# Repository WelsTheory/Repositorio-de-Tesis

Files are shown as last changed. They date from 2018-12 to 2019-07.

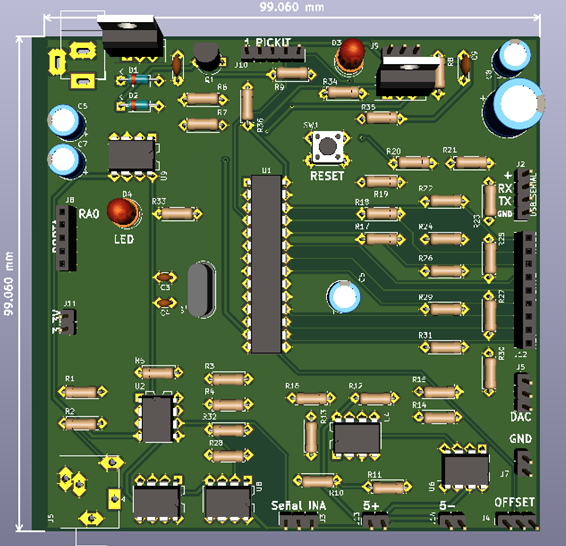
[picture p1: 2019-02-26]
Tarjeta de Adquisición de investigación.png

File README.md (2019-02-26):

# Diseño e implementación de un sistema de adquisición digital programable para señales ECG
Repositorio de la tesis "Diseño e implementación de un sistema de adquisición digital programable para señales ECG". Autor: William's Limonchi Sandoval
## Requisitos
Es necesario tener instalado los siguientes programas:
* [Matlab](https://www.mathworks.com/products/matlab.html) - La versión 2014 o superior
* [XC16](https://www.microchip.com/mplab/compilers) - El compilador XC16 para generar el programa del microcontrolador
* [Device Blocks for Simulink](https://www.microchip.com/forums/m878432.aspx) - Herramienta para trabajar con Microchip en Simulink
También es necesario tener la tarjeta de adquisición de la investigación para poder trabajar con el sistema. Los archivos de la tarjeta se encuentran en la carpeta Demo SAQD_ECG/Diseño Hardware_KiCad
### Carpetas del repositorio
* Carpeta de pruebas:
En esta carpeta se encuentran todos los ejemplos realizados antes de obtener el trabajo final
* Demo SAQD_ECG:
En esta carpeta se encuentra el programa principal de la tesis, desde el diseño de hardware de la investigación hasta el programa final con su interfaz gráfica.
* Ejemplos:
En esta carpeta se encuentran diferentes ejemplos que se han unido con el sistema. 
1) Downsamplin, para obtener otro tiempo de muestreos.
2) Filtros butterworth, para saber como trabajan los filtros butterworth con la investigación.
3) Filtros de 1er orden, son filtros sencillos de 1er orden para saber como trabaja la investigación
4) Sistema con tres filtros, es el programa principal con sólo 3 filtros.
5) Sistema con un único filtro, es el programa principal con un único filtro.
Estos programas son ejemplos para modificar el bloque Programable del programa principal. 
* Framework:
En esta carpeta se encuentra una copia del programa principal de la investigación, esto para poder modificar este programa sin necesidad de causar un error en el demo de la investigación.
## Contribución
Para contribuir con la investigación primero se debe hacer un fork al repositorio y seguidamente se puede enviar los cambios o modificaciones al correo: williams.limonchi.sandoval@gmail.com
## Version 
Esta investigación está en la versión 1.0.1 por lo que aún hay detalles que pulir y mejorar.
## Autor
William's Limonchi Sandoval [Twitter](http://twitter.com/welstheory)

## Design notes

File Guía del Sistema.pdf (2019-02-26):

Guía del Sistema

Para acceder a la investigación puedes entrar al siguiente enlace:

https://github.com/WelsTheory/Repositorio-de-Tesis o agregar el enlace ssh:

git@github.com:WelsTheory/Repositorio-de-Tesis.git para poder hacer un fork a la

investigación.

En la investigación encontrarás los siguientes archivos:

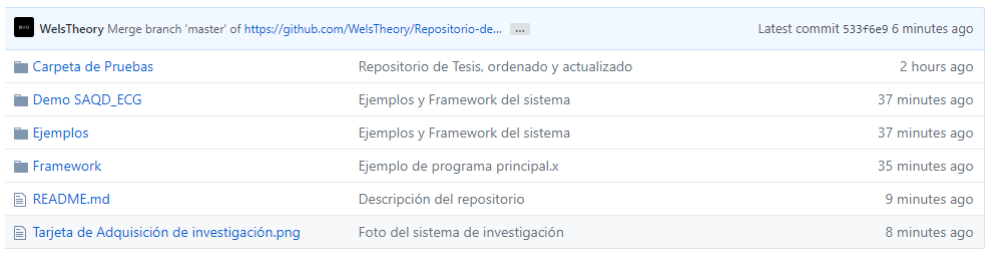
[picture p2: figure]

- Carpeta de pruebas: En esta carpeta se encuentran todos los ejemplos realizados

antes de obtener el trabajo final

- Demo SAQD_ECG: En esta carpeta se encuentra el programa principal de la tesis,

desde el diseño de hardware de la investigación hasta el programa final con su

interfaz gráfica.

- Ejemplos: En esta carpeta se encuentran diferentes ejemplos que se han unido con

el sistema.

✓ | Downsamplin, para obtener otro tiempo de muestreos.
✓ | Filtros butterworth, para s realizar prueba con los filtros butterworth y la
| investigación.
✓ | Filtros de 1er orden, son filtros sencillos de 1er orden para realizar prueba con
| la investigación
✓ | Sistema con tres filtros, es el programa principal con sólo 3 filtros.

✓ | Sistema con un único filtro, es el programa principal con un único filtro. Estos
| programas son ejemplos para modificar el bloque Programable del programa
| principal.
- Framework: En esta carpeta se encuentra una copia del programa principal de la

investigación, esto para poder modificar este programa sin necesidad de causar un

error en el demo de la investigación.

Requisitos:

Es necesario tener instalado los siguientes programas:

- Matlab (https://www.mathworks.com/products/matlab.html) - La versión 2014 o superior
- XC16 (https://www.microchip.com/mplab/compilers) - El compilador XC16 para generar el programa del microcontrolador
- Device Blocks for Simulink (https://www.microchip.com/forums/m878432.aspx) - Herramienta para trabajar con Microchip en Simulink

También es necesario tener la tarjeta de adquisición de la investigación para poder

trabajar con el sistema. Los archivos de la tarjeta se encuentran en la carpeta Demo

SAQD_ECG/Diseño Hardware_KiCad

Primeros pasos para programar el microcontrolador:

1) Abrir el programa Tesis_Simulink.slx que se encuentra en la carpeta Demo SAQD_ECG

para visualizar el programa completo y principal de la investigación:

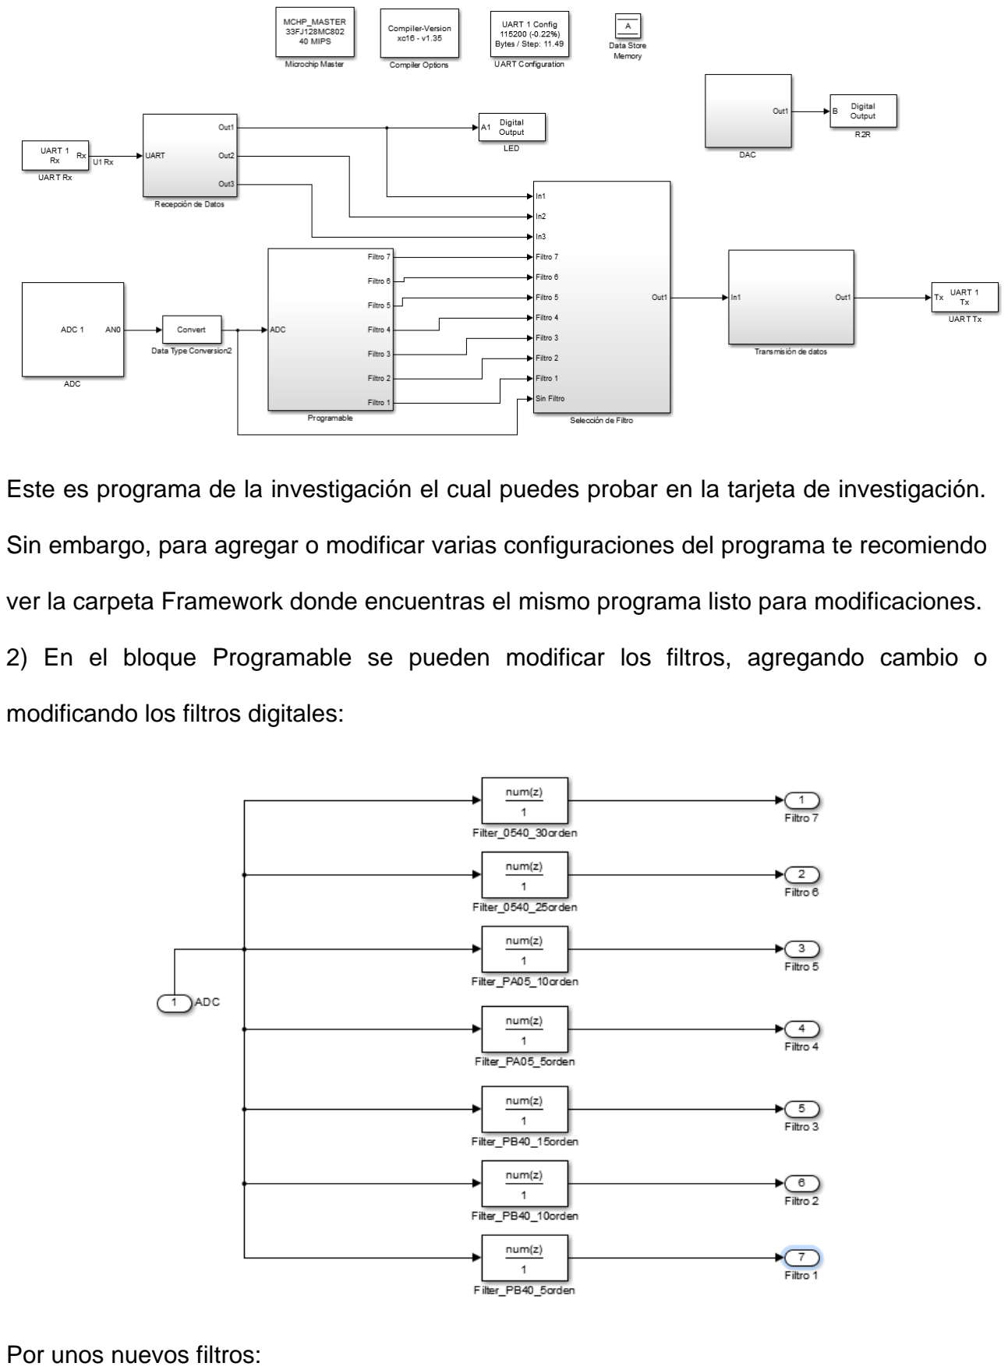
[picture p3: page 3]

Este es programa de la investigación el cual puedes probar en la tarjeta de investigación.

Sin embargo, para agregar o modificar varias configuraciones del programa te recomiendo

ver la carpeta Framework donde encuentras el mismo programa listo para modificaciones.

2) En el bloque Programable se pueden modificar los filtros, agregando cambio o

modificando los filtros digitales:

Por unos nuevos filtros:

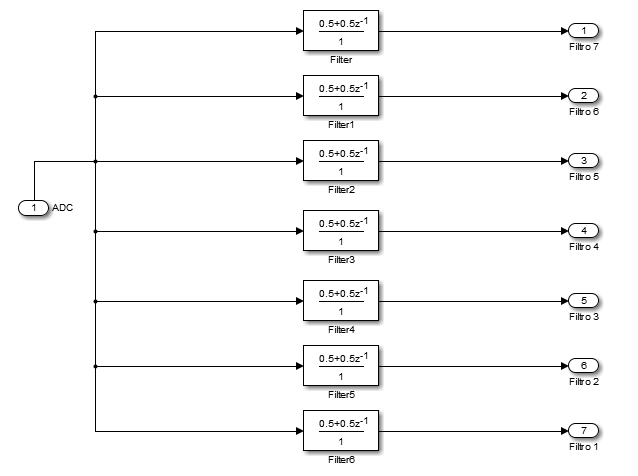
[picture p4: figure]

O quitando algunos filtros:

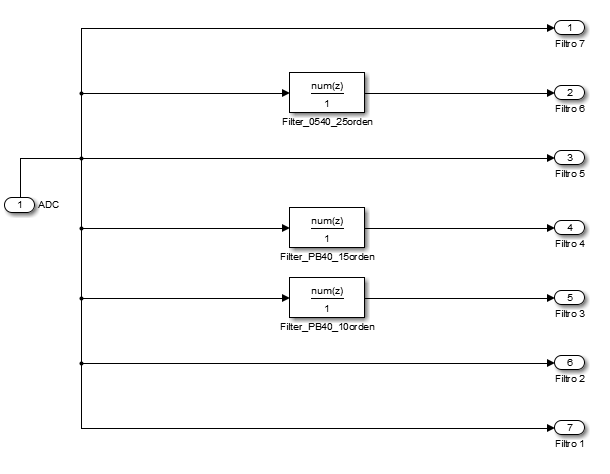
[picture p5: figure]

En la carpeta Ejemplos del repositorio, puedes encontrar más ejemplos de diferentes filtros

que se pueden utilizar o cambiar en el bloque Programable:

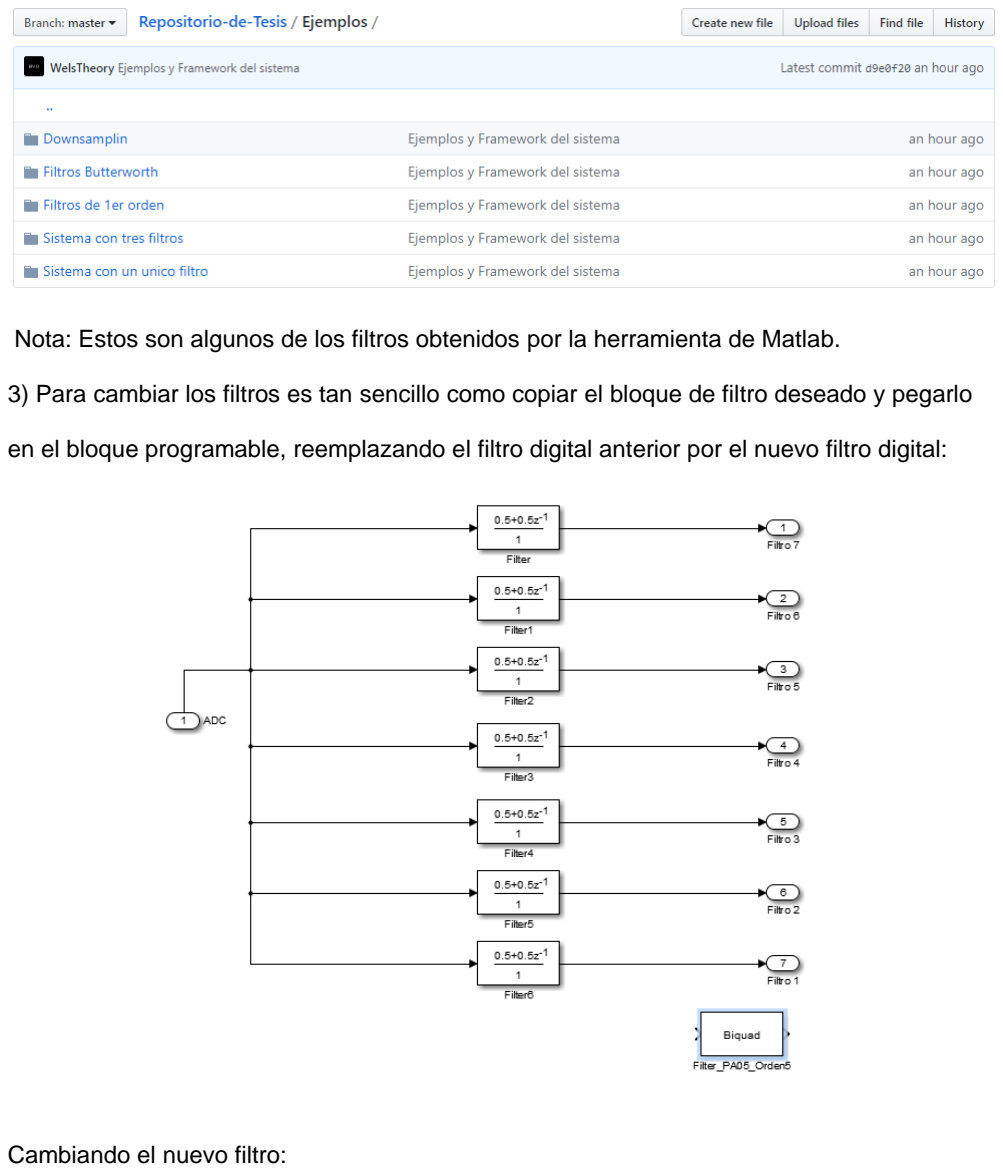
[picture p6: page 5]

Nota: Estos son algunos de los filtros obtenidos por la herramienta de Matlab.

3) Para cambiar los filtros es tan sencillo como copiar el bloque de filtro deseado y pegarlo

en el bloque programable, reemplazando el filtro digital anterior por el nuevo filtro digital:

Cambiando el nuevo filtro:

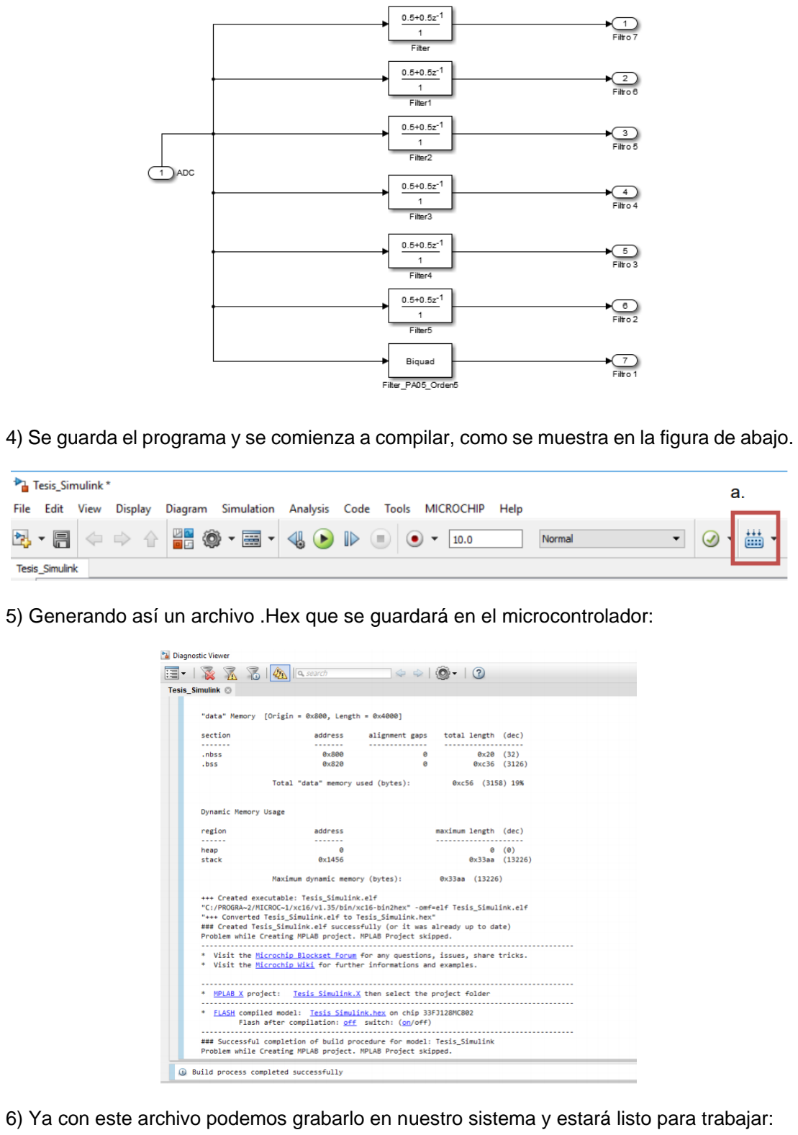
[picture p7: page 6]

4) Se guarda el programa y se comienza a compilar, como se muestra en la figura de abajo.
5) Generando así un archivo .Hex que se guardará en el microcontrolador:
6) Ya con este archivo podemos grabarlo en nuestro sistema y estará listo para trabajar:

Nota: Recordar que para este poder modificar el programa y los filtros es necesario

tener una versión de Matlab 2014 o superior, así como tener instalado el Compilador

XC16 de Microchip y Mplab 16-bit Device Blocks for Simulink v3.37 Released. Forum

Microchip

En la fecha de febrero del 2019 el programa se encuentra en la versión 1.0 por lo que

en el tiempo este apéndice puede ir modificándose.

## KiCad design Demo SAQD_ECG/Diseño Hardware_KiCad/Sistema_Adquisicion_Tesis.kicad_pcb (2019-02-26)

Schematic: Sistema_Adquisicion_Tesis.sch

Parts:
C1, C9: 100nF; C_Disc_D4.3mm_W1.9mm_P5.00mm
C2: 220uF; CP_Radial_D10.0mm_P5.00mm
C3, C4: 15pF; C_Disc_D3.0mm_W1.6mm_P2.50mm
C5, C6, C7, C8: 10uF; CP_Radial_D6.3mm_P2.50mm
D1, D2: 1N4148; D_DO-35_SOD27_P7.62mm_Horizontal
D3, D4: LED; LED_D5.0mm
J1: Barrel_Jack_Switch; Jack_Horizontal
J2: USB_SERIAL; PinHeader_1x04_P2.54mm_Vertical
J3: Signal_INA; PinHeader_1x03_P2.54mm_Vertical
J4: Offset; PinHeader_1x03_P2.54mm_Vertical
J5: Electrodos; Jack_3.5mm_Ledino_KB3SPRS_Horizontal
J6: DAC; PinHeader_1x03_P2.54mm_Vertical
J7: GND; PinHeader_1x02_P2.54mm_Vertical
J8: PORTA; PinSocket_1x05_P2.54mm_Vertical
J9: S_Fuente; PinHeader_1x03_P2.54mm_Vertical
J10: Pickit; PinHeader_1x05_P2.54mm_Vertical
J11: 3.3v; PinHeader_1x02_P2.54mm_Vertical
J12: PORTB; PinSocket_1x09_P2.54mm_Vertical
J13: V+; PinHeader_1x02_P2.54mm_Vertical
J14: V-; PinHeader_1x02_P2.54mm_Vertical
Q1: 2N3906; TO-92L_Inline_Wide
R1, R2: 1k; R_Axial_DIN0207_L6.3mm_D2.5mm_P7.62mm_Horizontal
R3, R4: 2k; R_Axial_DIN0207_L6.3mm_D2.5mm_P7.62mm_Horizontal
R5, R33, R35: 220; R_Axial_DIN0207_L6.3mm_D2.5mm_P7.62mm_Horizontal
R6, R7, R12: 5.6k; R_Axial_DIN0207_L6.3mm_D2.5mm_P7.62mm_Horizontal
R8, R19, R21, R23, R25, R27, R30, R36: 10k; R_Axial_DIN0207_L6.3mm_D2.5mm_P7.62mm_Horizontal
R9: 470; R_Axial_DIN0207_L6.3mm_D2.5mm_P7.62mm_Horizontal
R10, R11, R13, R14, R15, R16, R32: 1K; R_Axial_DIN0207_L6.3mm_D2.5mm_P7.62mm_Horizontal
R17, R18, R20, R22, R24, R26, R29, R31: 20k; R_Axial_DIN0207_L6.3mm_D2.5mm_P7.62mm_Horizontal
R28: 10K; R_Axial_DIN0207_L6.3mm_D2.5mm_P7.62mm_Horizontal
R34: 390; R_Axial_DIN0207_L6.3mm_D2.5mm_P7.62mm_Horizontal
SW1: RESET; SW_PUSH_6mm
U1: dsPIC33FJ128MC802-E_SP; DIP-28_W7.62mm
U2: INA128; DIP-8_W7.62mm
U3: L7805; TO-220-3_Vertical
U4, U7: TL082; DIP-8_W7.62mm
U5: LM317L_TO92; TO-220-3_Vertical
U6, U8: OP07; DIP-8_W7.62mm
U9: ADM660AN; DIP-8_W7.62mm
Y1: 10MHZ; Crystal_HC50_Vertical

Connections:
/3+: C9.1, J9.3, R35.2, U5.2
/3.3: J9.2, J11.1, J11.2, R36.2, U1.13, U1.28
/+IN: J5.T, J5.TN, R2.1
/-IN: J5.S, R1.1
/MCLR: J10.1, R36.1, SW1.1, U1.1
/OUT1: J3.2, R10.1
/OUT2: J4.3, U6.2, U6.6
/RA0: J4.2, J8.1, U1.2
/RA1: J8.2, R33.2, U1.3
/RA2: C3.1, J8.3, U1.9, Y1.1
/RA3: C4.1, J8.4, U1.10, Y1.2
/RA4: J8.5, U1.12
/RB0: J10.4, R18.1, U1.4
/RB1: J10.5, R20.1, U1.5
/RB2: R22.1, U1.6
/RB3: R24.1, U1.7
/RB4: R26.1, U1.11
/RB5: R29.1, U1.14
/RB6: R31.1, U1.15
/RB7: J12.1, U1.16
/RB8: J12.2, U1.17
/RB9: J12.3, U1.18
/RB12: J12.6, U1.23
/RB13: J12.7, U1.24
/RB14: J12.8, U1.25
/RB15: J12.9, U1.26
/RX: J2.2, J12.4, U1.21
/TC: J5.R, J5.RN, R28.1, U7.1
/TX: J2.3, J12.5, U1.22
/V+: C2.1, C8.1, D2.1, J13.1, J13.2, Q1.3, R9.1, R12.1, U2.7, U4.8 (V+), U5.3, U6.7, U7.8 (V+), U8.7, U9.8
/V-: C7.1, J14.1, J14.2, U2.4, U4.4 (V-), U6.4, U7.4 (V-), U8.4, U9.5
/Vp: J9.1, J10.2
/Vusb: J2.1, Q1.1, R8.1
/WCT: R3.1, R4.1, U8.3
GND: C1.2, C2.2, C3.2, C4.2, C5.1, C7.2, C8.2, C9.2, D1.1, D3.1, D4.1, J1.2, J1.3, J2.4, J3.1, J4.1, J6.1, J7.1, J7.2, J10.3, R6.2, R8.2, R15.2, R17.2, R34.1, SW1.2, U1.8, U1.19, U1.27, U2.5, U4.3 (+), U7.3 (+), U9.3
unnamed: C1.1, D2.2, R6.1, R7.1, U3.3
unnamed: C5.2, U1.20
unnamed: C6.1, U9.2
unnamed: C6.2, U9.4
unnamed: D1.2, U3.2
unnamed: D3.2, R9.2
unnamed: D4.2, R33.1
unnamed: J1.1, U3.1
unnamed: J3.3, U2.6
unnamed: J6.2, J6.3, R30.1, R31.2
unnamed: Q1.2, R7.2
unnamed: R1.2, U2.2
unnamed: R2.2, U2.3
unnamed: R3.2, R5.1, U2.1
unnamed: R4.2, R5.2, U2.8
unnamed: R10.2, R11.1, U4.2 (-)
unnamed: R11.2, R13.1, U4.1
unnamed: R12.2, R14.1, R15.1
unnamed: R13.2, R16.1, U4.6 (-)
unnamed: R14.2, U4.5 (+)
unnamed: R16.2, U4.7, U6.3
unnamed: R17.1, R18.2, R19.2
unnamed: R19.1, R20.2, R21.2
unnamed: R21.1, R22.2, R23.2
unnamed: R23.1, R24.2, R25.2
unnamed: R25.1, R26.2, R27.2
unnamed: R27.1, R29.2, R30.2
unnamed: R28.2, R32.1, U7.2 (-)
unnamed: R32.2, U8.2, U8.6
unnamed: R34.2, R35.1, U5.1

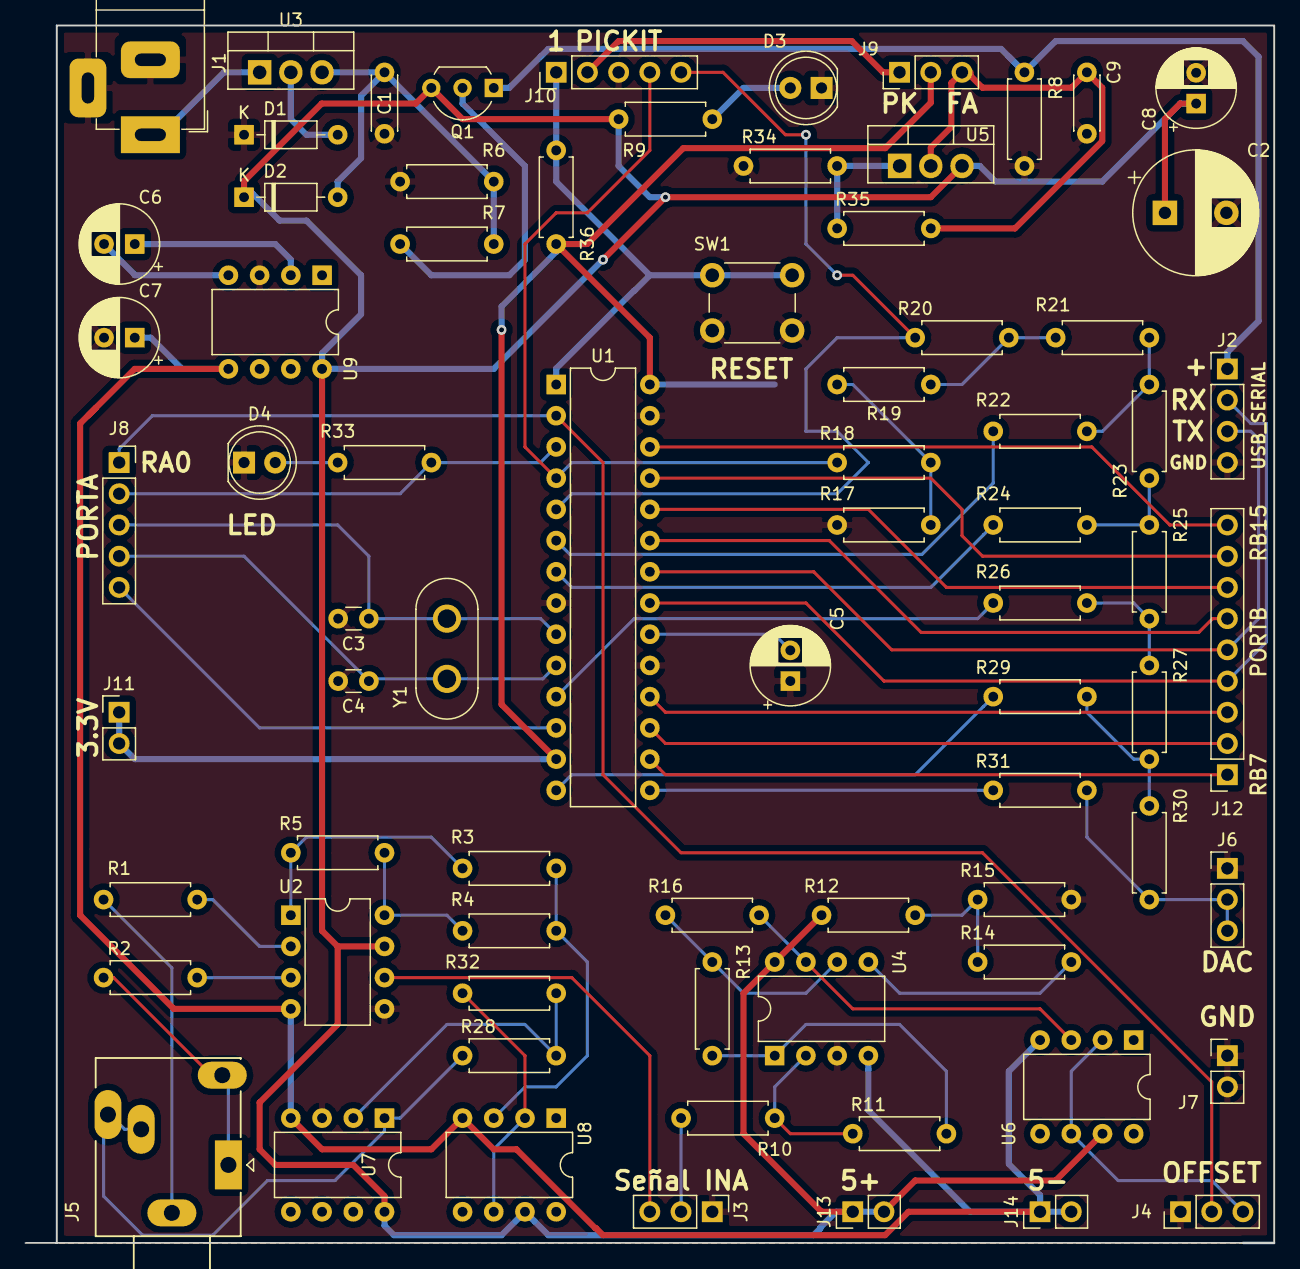
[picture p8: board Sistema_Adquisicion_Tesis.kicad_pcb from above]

Board: 2 copper layers, 101.6 x 99.1 mm, 75 parts (0 on the bottom side), 65 nets.

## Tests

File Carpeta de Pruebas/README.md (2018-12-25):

# Repositorio-de-Tesis
Diseño e implementación de un sistema de adquisición digital programable para señal ECG. Autor:William's Limonchi Sandoval

## Primeros pasos

Por el momento encontrarás una carpeta que se llama "Carpeta de Pruebas", en esta carpeta se está constantemente probando y desarrollando todos los programas para la versión final de la tesis. 

### Requisitos

Necesitas tener instalados algunos programas en tu computadora para iniciar:

```
Matlab desde la versión 2014 en adelante
Mplab Simulink (https://www.microchip.com/DevelopmentTools/ProductDetails/sw007023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)

```

### Plantilla para ir agregando en un futuro

A step by step series of examples that tell you how to get a development env running

Say what the step will be

```
Give the example
```

And repeat

```
until finished
```

End with an example of getting some data out of the system or using it for a little demo

## Running the tests

Explain how to run the automated tests for this system

### Break down into end to end tests

Explain what these tests test and why

```
Give an example
```

### And coding style tests

Explain what these tests test and why

```
Give an example
```

## Deployment

Add additional notes about how to deploy this on a live system

## Built With

* [Dropwizard](http://www.dropwizard.io/1.0.2/docs/) - The web framework used
* [Maven](https://maven.apache.org/) - Dependency Management
* [ROME](https://rometools.github.io/rome/) - Used to generate RSS Feeds

## Contributing

Please read [CONTRIBUTING.md](https://gist.github.com/PurpleBooth/b24679402957c63ec426) for details on our code of conduct, and the process for submitting pull requests to us.

## Versioning

We use [SemVer](http://semver.org/) for versioning. For the versions available, see the [tags on this repository](https://github.com/your/project/tags). 

## Authors

* **Billie Thompson** - *Initial work* - [PurpleBooth](https://github.com/PurpleBooth)

See also the list of [contributors](https://github.com/your/project/contributors) who participated in this project.

## License

This project is licensed under the MIT License - see the [LICENSE.md](LICENSE.md) file for details

## Acknowledgments

* Hat tip to anyone whose code was used
* Inspiration
* etc

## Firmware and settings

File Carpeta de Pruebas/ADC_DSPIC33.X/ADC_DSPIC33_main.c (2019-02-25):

/*
 * -------------------------------------------------------------------
 * MPLAB 16-Bit Device Blocks for Simulink v3.38.
 *
 *   Product Page:  http://www.microchip.com/SimulinkBlocks
 *           Forum: http://www.microchip.com/forums/f192.aspx
 *           Wiki:  http://microchip.wikidot.com/simulink:start
 * -------------------------------------------------------------------
 * File: ADC_DSPIC33_main.c
 *
 * Code generated for Simulink model 'ADC_DSPIC33'.
 *
 * Model version                  : 1.202
 * Simulink Coder version         : 8.6 (R2014a) 27-Dec-2013
 * C/C++ source code generated on : Sun Nov 18 19:15:44 2018
 */

#define MCHP_isMainFile
#include "ADC_DSPIC33.h"
#include "ADC_DSPIC33_private.h"

volatile uint_T ContinueTimeStep __attribute__ ((near)) = 0;/* Microchip Global Variable for single rate scheduler */

/* Microchip Global Variables */
/* Set Fuses Options */
#pragma config FNOSC = PRI, IESO = OFF
#pragma config POSCMD = HS, FCKSM = CSECMD
#pragma config FWDTEN = OFF
#pragma config FPWRT = PWR1
#pragma config JTAGEN = OFF

/* Solver mode : SingleTasking */
int main()
{
  /* Initialize model */
  /* Start Clock Switching */
  if ((OSCCONbits.COSC & 1) && !(OSCCONbits.COSC & 4))/* check not already in PLL mode (0?1) */
  {
    __builtin_write_OSCCONH(0);        /* Clock Switch to non PLL mode */
    __builtin_write_OSCCONL(0x01);     /* Start clock switching */
    __asm__ volatile("nop\n"
                     "nop");
    while (OSCCONbits.COSC != 0) ;
  }

  PLLFBD = 110.0;                      /* configure Oscillator PLL : PLLDIV */
  CLKDIV = 0x05;                       /* configure Oscillator PLL : FRCDIV ; PLLPOST ; PLLPRE */
  __builtin_write_OSCCONH(3);          /* Clock Switch to desired configuration */
  __builtin_write_OSCCONL(0x01);       /* Start clock switching */

  /* Configure Pins as Analog or Digital */
  AD1PCFGL = 0x1A;

  /* Configure Remappables Pins */
  RPINR18 = 0x0A;
  RPOR5 = 0x0300;

  /* Configure Digitals I/O directions */
  TRISA = 0xFFFD;
  TRISB = 0xF7F9;

  /* Finish clock switching procedure */
  while (OSCCONbits.COSC != 3) ;       /* Wait for Oscillator Stabilisation */
  while (OSCCONbits.LOCK != 1) ;       /* Wait for PLL Stabilisation */

  /* Initialize model */
  ADC_DSPIC33_initialize();

  /* Configure Timers */
  /* --- TIMER 3 --- This timer is enabled at end of configuration functions. */
  T3CON = 0;                           /* Stop Timer 3 and resets control register */
  PR3 = 0x9C3F;                        /* Period */

  /* Enable Time-step */
  _T3IF = 0;                           /* Clear Timer 3 Interrupt flag */
  _T3IE = 1;                           /* Enable Timer 3 model Step Interrupt */
  TMR3 = 0x9C3E;
  T3CONbits.TON = 1;                   /* Start timer 3. Timer 3 is the source trigger for the model Time-step */

  /* Main Loop */
  for (;;) {
    while (!ContinueTimeStep) ;

    /* Disable Scheduler Interrupt */
    _IPL0 = 1;                         /* Disable Scheduler Interrupts. Rise IPL from 0 to 1 */
    __asm__ volatile ("BCLR.b %[MyVar], #0" : [MyVar] "+m" (ContinueTimeStep) );/* Atomic bit-clear of ContinueTimeStep bit 1 */

    /* Call model Scheduler */
    /* Step the model for base rate */
    /* Start profiling task 0 */
    ADC_DSPIC33_step();

    /* Get model outputs here */

    /* Stop profiling task 0 */

    /* Re-Enable Scheduler Interrupt */
    _IPL0 = 0;                         /* Re-Enable Scheduler re-entrant interrupt. Lower IPL from 1 to 0 */
  }                                    /* End for(;;) */
}

/*
 * File trailer for generated code.
 *
 * [EOF]
 */

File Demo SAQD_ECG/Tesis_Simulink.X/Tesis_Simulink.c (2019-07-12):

/*
 * -------------------------------------------------------------------
 * MPLAB 16-Bit Device Blocks for Simulink v3.38.
 *
 *   Product Page:  http://www.microchip.com/SimulinkBlocks
 *           Forum: http://www.microchip.com/forums/f192.aspx
 *           Wiki:  http://microchip.wikidot.com/simulink:start
 * -------------------------------------------------------------------
 * File: Tesis_Simulink.c
 *
 * Code generated for Simulink model 'Tesis_Simulink'.
 *
 * Model version                  : 1.143
 * Simulink Coder version         : 8.6 (R2014a) 27-Dec-2013
 * C/C++ source code generated on : Sun Jul 07 20:59:31 2019
 */

#include "Tesis_Simulink.h"
#include "Tesis_Simulink_private.h"

/* Block signals and states (auto storage) */
DW_Tesis_Simulink_T Tesis_Simulink_DW;

/* Model step function */
void Tesis_Simulink_step(void)
{
  /* local block i/o variables */
  boolean_T rtb_Compare;
  real32_T numAccum;
  real32_T denAccum;
  int32_T i;
  int32_T j;
  boolean_T rtb_Compare_m;
  real32_T rtb_DataTypeConversion7;
  real32_T rtb_Filtro_40Hz_Orden_20;
  real32_T rtb_Filtro_05Hz_Orden_2;
  real32_T rtb_Filtro_40Hz_Orden_5;
  real32_T rtb_Filtro_40Hz_Orden_15;
  real32_T rtb_Filtro_40Hz_Orden_30;

  /* MCHP_UART_Rx Block for UARTRef 1: <Root>/UART Rx/Outputs */
  {
    static uint8_T U1LastValue ;
    if (0U != U1STAbits.URXDA) {       /* Flush internal UART buffer */
      uint_T Tmp;
      _U1RXIE = 0;                     /* Flush internal UART buffer, disable interrupt */
      Tmp = ~(MCHP_UART1_Rx.tail - MCHP_UART1_Rx.head);/* head - tail - 1 */
      Tmp &= (Rx_BUFF_SIZE_Uart1-1);   /* Tmp =  (head - tail - 1) modulo buffersize Rx_BUFF_SIZE_Uart1)	<==> Rx_BUFF_SIZE_Uart1 - (head - tail) - 1*/
      while (U1STAbits.URXDA == 1) {
        if (Tmp--) {
          MCHP_UART1_Rx.buffer[MCHP_UART1_Rx.tail] = (uint8_T) U1RXREG;
          MCHP_UART1_Rx.tail = (MCHP_UART1_Rx.tail+1) & (Rx_BUFF_SIZE_Uart1-1);
        } else {
          unsigned int a;
          do
            a = U1RXREG;
          while (U1STAbits.URXDA == 1);
          break;
        }
      }

      _U1RXIF = 0;                     /* Reset interrupt */
      _U1RXIE = 1;                     /* Re-enable interrupt */
    }

    if (MCHP_UART1_Rx.tail != MCHP_UART1_Rx.head) {
      Tesis_Simulink_DW.U1Rx = (uint8_T) MCHP_UART1_Rx.buffer[MCHP_UART1_Rx.head];/* Use only the 8 low bytes or RxReg */
      MCHP_UART1_Rx.head = (MCHP_UART1_Rx.head+1) & (Rx_BUFF_SIZE_Uart1-1);
      U1LastValue = Tesis_Simulink_DW.U1Rx;
    } else {
      Tesis_Simulink_DW.U1Rx = U1LastValue;
      if (U1STAbits.OERR )
        U1STAbits.OERR = 0;            /* Clear UART Rx Overload Error */
    }
  }

  /* RelationalOperator: '<S6>/Compare' incorporates:
   *  Constant: '<S6>/Constant'
   *  S-Function (sfix_bitop): '<S3>/Bitwise Operator2'
   */
  rtb_Compare = ((Tesis_Simulink_DW.U1Rx & 1) == 1);

  /* S-Function (MCHP_Digital_Output_Write): '<S1>/Digital Output Write' */
  LATAbits.LATA1 = rtb_Compare;

  /* MCHP_ADC Block for ADC 1: <Root>/ADC/Output */
  Tesis_Simulink_DW.ADC = ADC1BuffChannelA[0];

  /* DataTypeConversion: '<Root>/Data Type Conversion2' */
  Tesis_Simulink_DW.DataTypeConversion2 = Tesis_Simulink_DW.ADC;

  /* S-Function (sdspbiquad): '<S2>/Filtro_40Hz_Orden_5but' */
  denAccum = (0.0151201887F * Tesis_Simulink_DW.DataTypeConversion2 -
              -1.86462557F *
              Tesis_Simulink_DW.Filtro_40Hz_Orden_5but_FILT_STATES[0L]) -
    0.925106287F * Tesis_Simulink_DW.Filtro_40Hz_Orden_5but_FILT_STATES[1L];
  numAccum = (2.0F * Tesis_Simulink_DW.Filtro_40Hz_Orden_5but_FILT_STATES[0L] +
              denAccum) + Tesis_Simulink_DW.Filtro_40Hz_Orden_5but_FILT_STATES
    [1L];
  Tesis_Simulink_DW.Filtro_40Hz_Orden_5but_FILT_STATES[1L] =
    Tesis_Simulink_DW.Filtro_40Hz_Orden_5but_FILT_STATES[0L];
  Tesis_Simulink_DW.Filtro_40Hz_Orden_5but_FILT_STATES[0L] = denAccum;
  denAccum = (0.0141148167F * numAccum - -1.74064279F *
              Tesis_Simulink_DW.Filtro_40Hz_Orden_5but_FILT_STATES[2L]) -
    0.797102034F * Tesis_Simulink_DW.Filtro_40Hz_Orden_5but_FILT_STATES[3L];
  numAccum = (2.0F * Tesis_Simulink_DW.Filtro_40Hz_Orden_5but_FILT_STATES[2L] +
              denAccum) + Tesis_Simulink_DW.Filtro_40Hz_Orden_5but_FILT_STATES
    [3L];
  Tesis_Simulink_DW.Filtro_40Hz_Orden_5but_FILT_STATES[3L] =
    Tesis_Simulink_DW.Filtro_40Hz_Orden_5but_FILT_STATES[2L];
  Tesis_Simulink_DW.Filtro_40Hz_Orden_5but_FILT_STATES[2L] = denAccum;
  denAccum = (0.0133592F * numAccum - -1.64746F *
              Tesis_Simulink_DW.Filtro_40Hz_Orden_5but_FILT_STATES[4L]) -
    0.7008968F * Tesis_Simulink_DW.Filtro_40Hz_Orden_5but_FILT_STATES[5L];
  numAccum = (2.0F * Tesis_Simulink_DW.Filtro_40Hz_Orden_5but_FILT_STATES[4L] +
              denAccum) + Tesis_Simulink_DW.Filtro_40Hz_Orden_5but_FILT_STATES
    [5L];
  Tesis_Simulink_DW.Filtro_40Hz_Orden_5but_FILT_STATES[5L] =
    Tesis_Simulink_DW.Filtro_40Hz_Orden_5but_FILT_STATES[4L];
  Tesis_Simulink_DW.Filtro_40Hz_Orden_5but_FILT_STATES[4L] = denAccum;
  denAccum = (0.0128590548F * numAccum - -1.58578193F *
              Tesis_Simulink_DW.Filtro_40Hz_Orden_5but_FILT_STATES[6L]) -
    0.637218118F * Tesis_Simulink_DW.Filtro_40Hz_Orden_5but_FILT_STATES[7L];
  numAccum = (2.0F * Tesis_Simulink_DW.Filtro_40Hz_Orden_5but_FILT_STATES[6L] +
              denAccum) + Tesis_Simulink_DW.Filtro_40Hz_Orden_5but_FILT_STATES
    [7L];
  Tesis_Simulink_DW.Filtro_40Hz_Orden_5but_FILT_STATES[7L] =
    Tesis_Simulink_DW.Filtro_40Hz_Orden_5but_FILT_STATES[6L];
  Tesis_Simulink_DW.Filtro_40Hz_Orden_5but_FILT_STATES[6L] = denAccum;
  denAccum = (0.0126108425F * numAccum - -1.55517232F *
              Tesis_Simulink_DW.Filtro_40Hz_Orden_5but_FILT_STATES[8L]) -
    0.605615675F * Tesis_Simulink_DW.Filtro_40Hz_Orden_5but_FILT_STATES[9L];
  Tesis_Simulink_DW.Filtro_40Hz_Orden_5but = (2.0F *
    Tesis_Simulink_DW.Filtro_40Hz_Orden_5but_FILT_STATES[8L] + denAccum) +
    Tesis_Simulink_DW.Filtro_40Hz_Orden_5but_FILT_STATES[9L];
  Tesis_Simulink_DW.Filtro_40Hz_Orden_5but_FILT_STATES[9L] =
    Tesis_Simulink_DW.Filtro_40Hz_Orden_5but_FILT_STATES[8L];
  Tesis_Simulink_DW.Filtro_40Hz_Orden_5but_FILT_STATES[8L] = denAccum;

  /* DataTypeConversion: '<S3>/Data Type Conversion7' incorporates:
   *  Constant: '<S8>/Constant'
   *  Product: '<S3>/Divide2'
   *  RelationalOperator: '<S8>/Compare'
   *  S-Function (sfix_bitop): '<S3>/Bitwise Operator1'
   */
  rtb_DataTypeConversion7 = ((Tesis_Simulink_DW.U1Rx & 4) >> 2 == 1);

  /* DiscreteFir: '<S2>/Filtro_40Hz_Orden_20' */
  /* Consume delay line and beginning of input samples */
  for (i = 1L; i - 1L < 1L; i++) {
    rtb_Filtro_40Hz_Orden_20 = 0.0F;
    for (j = 0L; j < i; j++) {
      rtb_Filtro_40Hz_Orden_20 += Tesis_Simulink_DW.DataTypeConversion2 *
        Tesis_Simulink_ConstP.Filtro_40Hz_Orden_20_Coefficients[j];
    }
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

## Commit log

2018-12-25 Carpeta de Pruebas y Plantilla de Readme
    [COEF.xlsx, ECG-LISTA-MATLAB-010618.csv, ECG_Cabana_12v.csv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]
2018-12-25 Plantilla de Readme
2018-12-26 Versión 1.0 de la Tesis
2019-02-25 Repositorio de tesis 1.0.0.0.1
    [ECG_Cabana_12v.csv, ECG_Cabana_3-3v.csv, ECG_Cabana_5v.csv]
2019-02-26 Repositorio de Tesis, ordenado y actualizado
    [ECG_Wels.csv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]
2019-02-26 Ejemplos y Framework del sistema
2019-02-26 Ejemplo de programa principal.x
2019-02-26 Foto del sistema de investigación
2019-07-12 Repositorio de Tesis
    [ECG_Francisco_INA220.CSV, ECG_data.csv]
